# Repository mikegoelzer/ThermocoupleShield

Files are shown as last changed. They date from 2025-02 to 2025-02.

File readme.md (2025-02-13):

# Arduino K-Type Thermocouple Shield

<div align="center">
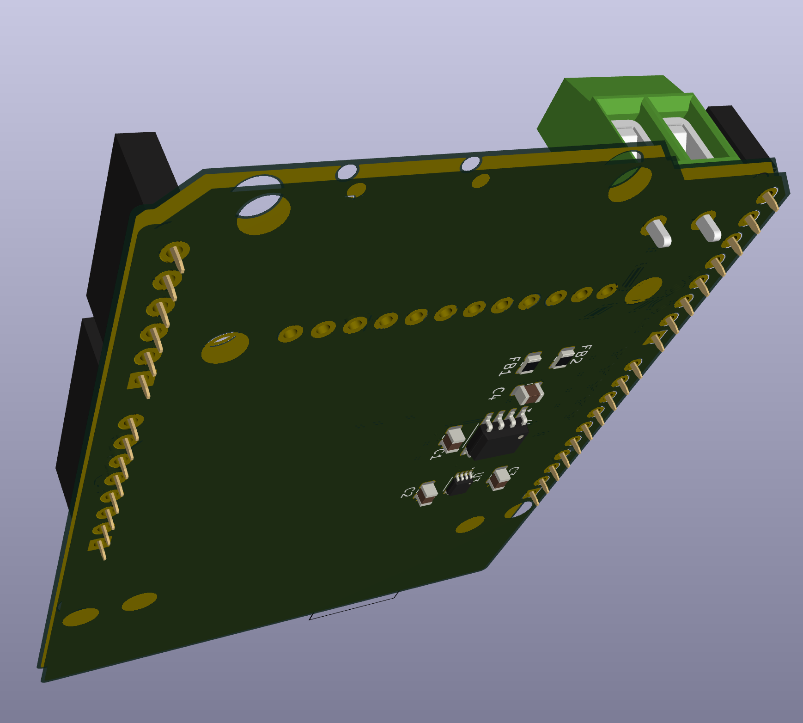
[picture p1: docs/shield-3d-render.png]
3D render of the thermocouple shield
  
</div>

## Description

Arduino Uno shield designed to interface with K-type thermocouples using the MAX31855 cold-junction compensated thermocouple-to-digital converter.

## Features

- Compatible with Arduino Uno form factor
- Uses MAX31855 for K-type thermocouple interface
- Display screen with Arduino sketch for displaying temperature
- Temperature range: -200°C to +1350°C

## Repository Contents

- `/hardware` - KiCad project files and custom parts
- `/doc` - documentation and images
- `/bom` - bill of materials spreadsheets
- 

## Hardware Requirements

- Arduino Uno or compatible board
- K-type thermocouple
- This shield PCB

## License

This hardware design is released under the [CERN Open Hardware License v2 - Strongly Reciprocal](https://ohwr.org/cern_ohl_s_v2.txt).

## Contributing

Contributions to improve the design are welcome. Please submit issues and pull requests.

# Credits

Circuit inspired by [Adafruit #269](https://www.adafruit.com/product/269)

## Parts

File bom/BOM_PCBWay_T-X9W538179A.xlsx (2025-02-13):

 |  |  | T-X9W538179A 01PCS BOM
Item # | *Designator | *Qty | Manufacturer | *Mfg Part # | Description / Value | *Package/Footprint | Type | Your Instructions / Notes
1 | U2 | 1 | Knitter-Switch | PLSJ 1 | SWITCH TACT 10MA 5V | Custom footprint | SMD
2 | U1 | 1 | Analog Devices Inc./Maxim Integrated | MAX31855KASA+T | IC CONV THERMOCOUPLE-DGTL SOIC | 8-SOIC | SMD
3 | C1,C2,C3 | 3 | YAGEO | CC0805KRX7R9BB104 | CAP CER 0.1UF 50V X7R 0805 | 0805 | SMD
4 | C4 | 1 | KEMET | C0805C103K5RACTU | CAP CER 10000PF 50V X7R 0805 | 0805 | SMD
5 | FB1,FB2 | 2 | Würth Elektronik | 74279220601 | FERRITE BEAD 600 OHM 0805 1LN | 0805 | SMD
6 | J6 | 1 | Würth Elektronik | 691137710002 | TERM BLK 2POS SIDE ENTRY 5MM PCB | Custom footprint | THT
7 | U3 | 1 | Texas Instruments | TXB0102DCUR | IC TRANSLTR BIDIRECTIONAL 8VSSOP | 8-VSSOP | SMD
Need a quick and accurante quote? Need an efficient production? Please read SMT Ordering Necessary Files & Info in 1 minute. Thank you very much! (https://www.pcbway.com/smt_ordering_guide.html)
Click for Instructions on How to Create a BOM (https://www.pcbway.com/blog/PCB_Assembly/How_to_Build_a_BOM__Bill_Of_Materials_.html)

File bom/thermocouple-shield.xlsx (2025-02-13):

Desc | Parts | Actual Qty | Order Qty | (Override Qty) | Order Qtr | Price | Subtotal | In basket? | Vendor URL | Mfgr | MPN | Notes
Thermocouple Shield Rev 1
# of boards | 2
CONN RCPT 10POS 0.1 GOLD PCB | J2 | 1 | 2 |  | 2 | $2.02 | $4.04 | ✅ | https://www.digikey.com/en/products/detail/samtec-inc/SSQ-110-03-F-S/6678747 | Samtec | SSQ-110-03-F-S
CONN RCPT 8POS 0.1 GOLD PCB | J1,J4 | 2 | 4 |  | 4 | $1.86 | $7.44 | ✅ | https://www.digikey.com/en/products/detail/samtec-inc/SSQ-108-03-F-S/6692119 | Samtec | SSQ-108-03-F-S
CONN RCPT 6POS 0.1 GOLD PCB | J3 | 1 | 2 |  | 2 | $1.40 | $2.80 | ✅ | https://www.digikey.com/en/products/detail/samtec-inc/SSQ-106-03-F-S/6678741 | Samtec | SSQ-106-03-F-S
RECEPTACLE STRIP 12P 2.54MM PITC | J5 | 1 | 2 |  | 2 | $1.40 | $2.80 | ✅ | https://www.digikey.com/en/products/detail/adam-tech/RS1-12-G/9832041 | Adam Tech | RS1-12-G

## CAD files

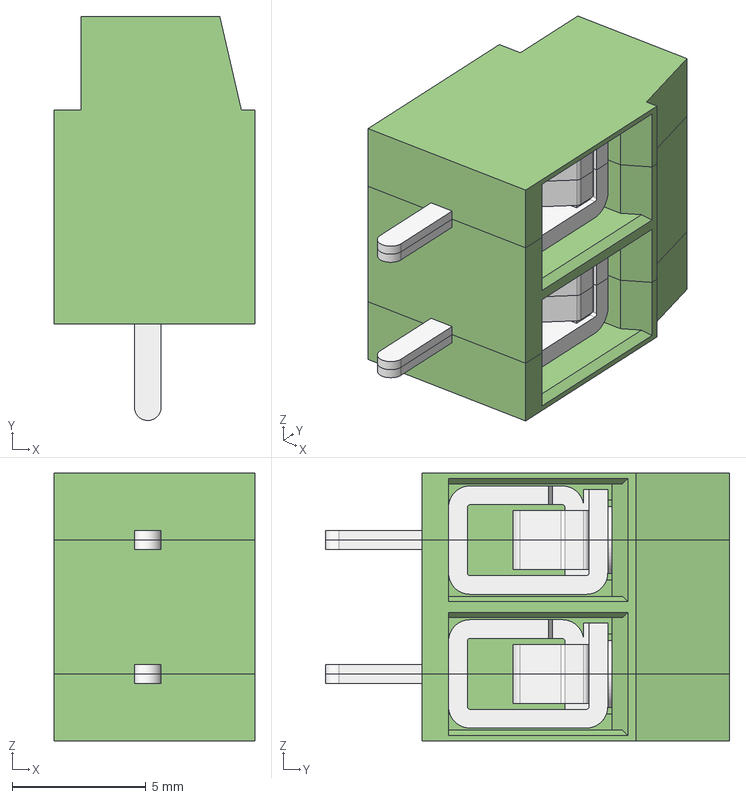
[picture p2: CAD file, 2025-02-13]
hardware/parts/691137710002/691137710002.step
7.50 x 15.1 x 10.0 mm
MRT12P5_SX
MRT12P5_CNT
MRT12P5_DX

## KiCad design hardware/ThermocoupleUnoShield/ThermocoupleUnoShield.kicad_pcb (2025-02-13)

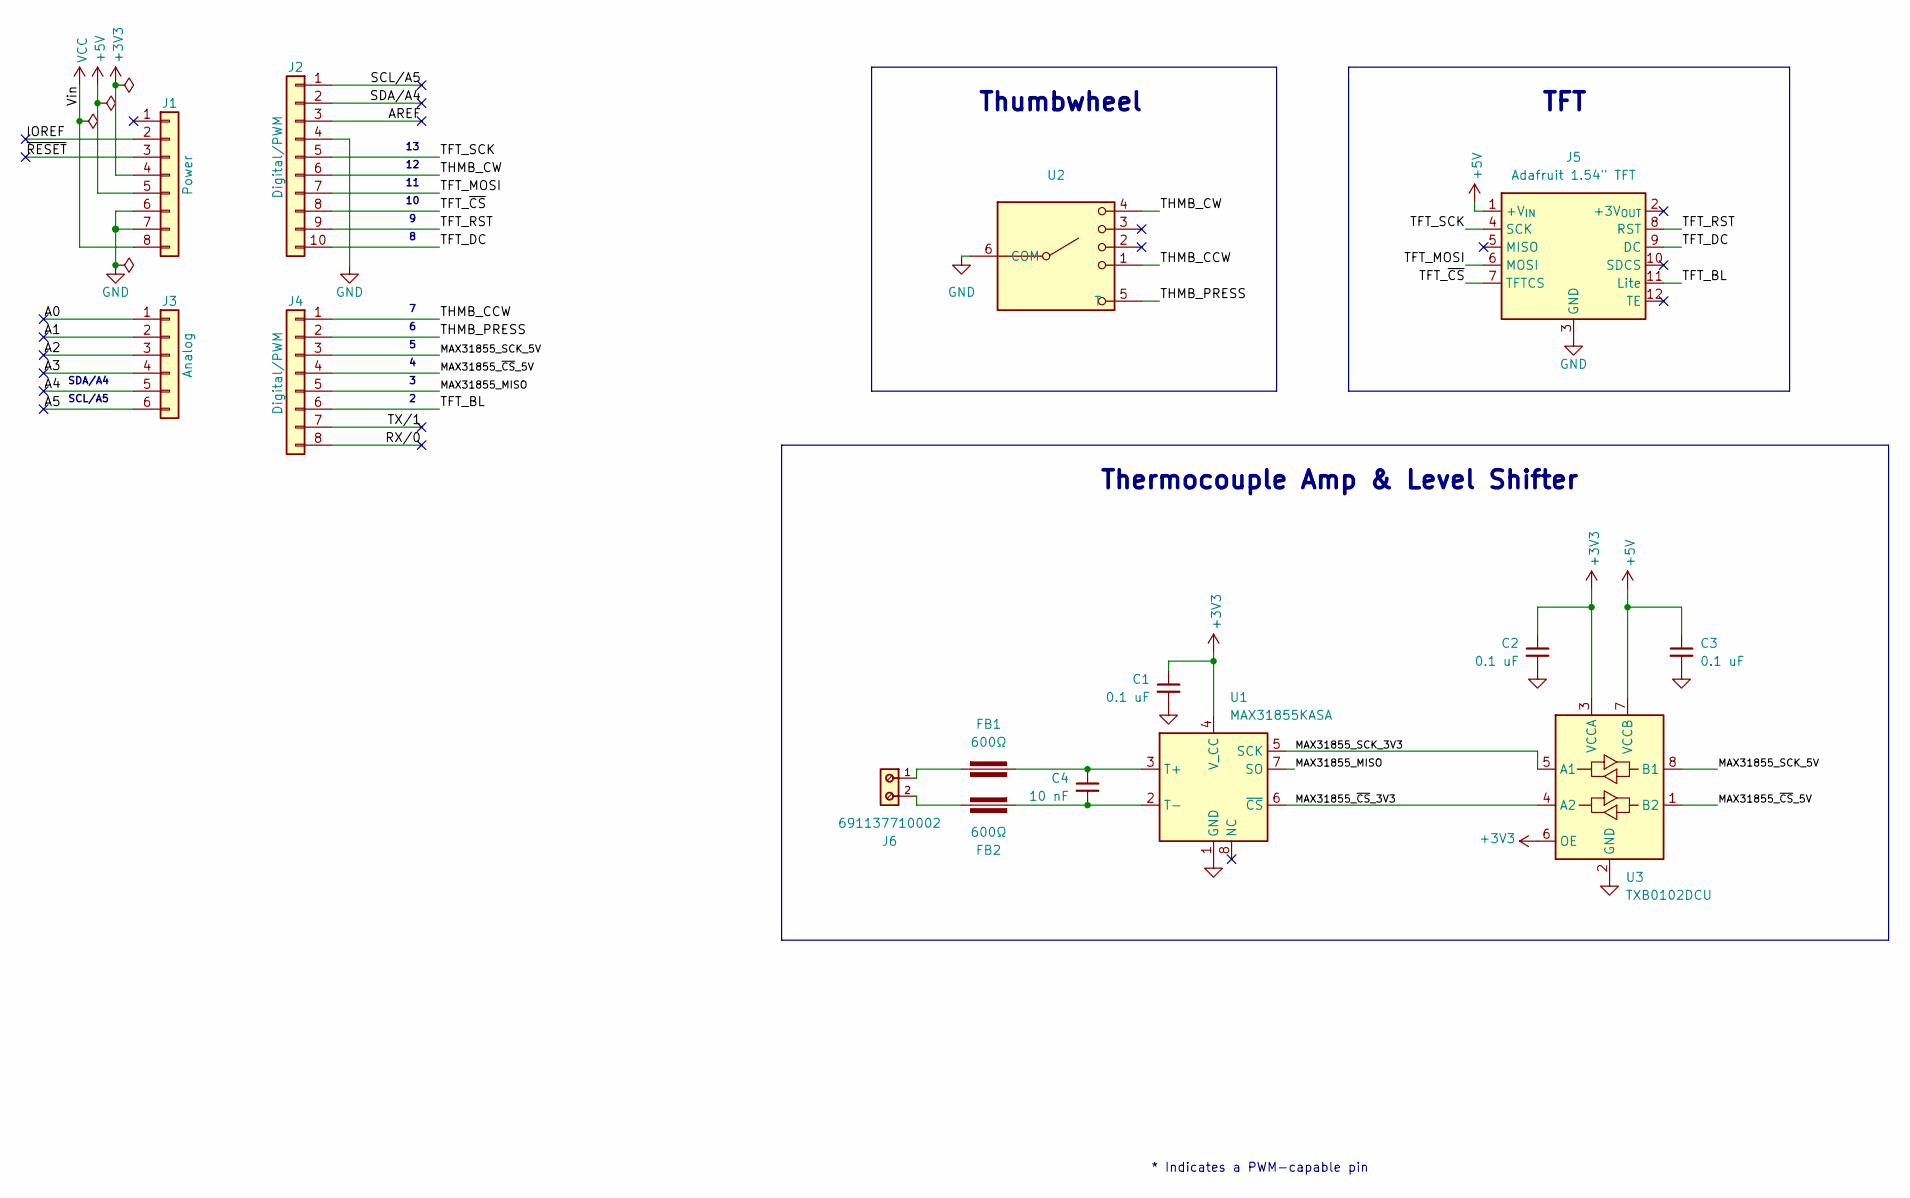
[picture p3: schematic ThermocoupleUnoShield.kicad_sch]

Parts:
C1, C2, C3: 0.1 uF; C_0805_2012Metric; MPN CC0805KRX7R9BB104
C4: 10 nF; C_0805_2012Metric; MPN C0805C103K5RACTU
FB1, FB2: 600Ω; Fuse_0805_2012Metric; MPN 74279220601
J1: Power; PinSocket_1x08_P2.54mm_Vertical; MPN SSQ-108-03-F-S
J2: Digital/PWM; PinSocket_1x10_P2.54mm_Vertical; MPN SSQ-110-03-F-S
J3: Analog; PinSocket_1x06_P2.54mm_Vertical; MPN SSQ-106-03-F-S
J4: Digital/PWM; PinSocket_1x08_P2.54mm_Vertical; MPN SSQ-108-03-F-S
J5: Adafruit 1.54" TFT; 1.54 TFT 240x240; MPN 3787
J6: 691137710002; PART-NUMBER 691137710002
U1: MAX31855KASA; SOIC-8_3.9x4.9mm_P1.27mm; MPN MAX31855KASA+T
U2: PLSJ1; MPN PLSJ 1
U3: TXB0102DCU; VSSOP-8_2.4x2.1mm_P0.5mm; MPN TXB0102DCUR

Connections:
+3V3: C1.1, C2.1, J1.4, U1.4 (V_CC), U3.3 (VCCA), U3.6 (OE)
+5V: C3.1, J1.5, J5.1 (+V_{IN}), U3.7 (VCCB)
/A0: J3.1
/A1: J3.2
/A2: J3.3
/A3: J3.4
/A4: J3.5
/A5: J3.6
/AREF: J2.3
/IOREF: J1.2
/MAX31855_MISO: J4.5, U1.7 (SO)
/MAX31855_SCK_3V3: U1.5 (SCK), U3.5 (A1)
/MAX31855_SCK_5V: J4.3, U3.8 (B1)
/MAX31855_~CS_3V3: U1.6 (~CS), U3.4 (A2)
/MAX31855_~CS_5V: J4.4, U3.1 (B2)
/RX/0: J4.8
/SCL/A5: J2.1
/SDA/A4: J2.2
/TFT_BL: J4.6, J5.11 (Lite)
/TFT_DC: J2.10, J5.9 (DC)
/TFT_MOSI: J2.7, J5.6 (MOSI)
/TFT_RST: J2.9, J5.8 (RST)
/TFT_SCK: J2.5, J5.4 (SCK)
/TFT_~CS: J2.8, J5.7 (TFTCS)
/THMB_CCW: J4.1, U2.1
/THMB_CW: J2.6, U2.4
/THMB_PRESS: J4.2, U2.5 (T)
/TX/1: J4.7
/~RESET: J1.3
GND: C1.2, C2.2, C3.2, J1.6, J1.7, J2.4, J5.3 (GND), U1.1 (GND), U2.6 (COM), U3.2 (GND)
unnamed: FB1.1, J6.1
unnamed: FB2.2, J6.2
unnamed: C4.1, FB1.2, U1.3 (T+)
unnamed: C4.2, FB2.1, U1.2 (T-)
VCC: J1.8

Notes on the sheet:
Thumbwheel
TFT
SCL/A5
* Indicates a PWM-capable pin
SDA/A4
Thermocouple Amp & Level Shifter

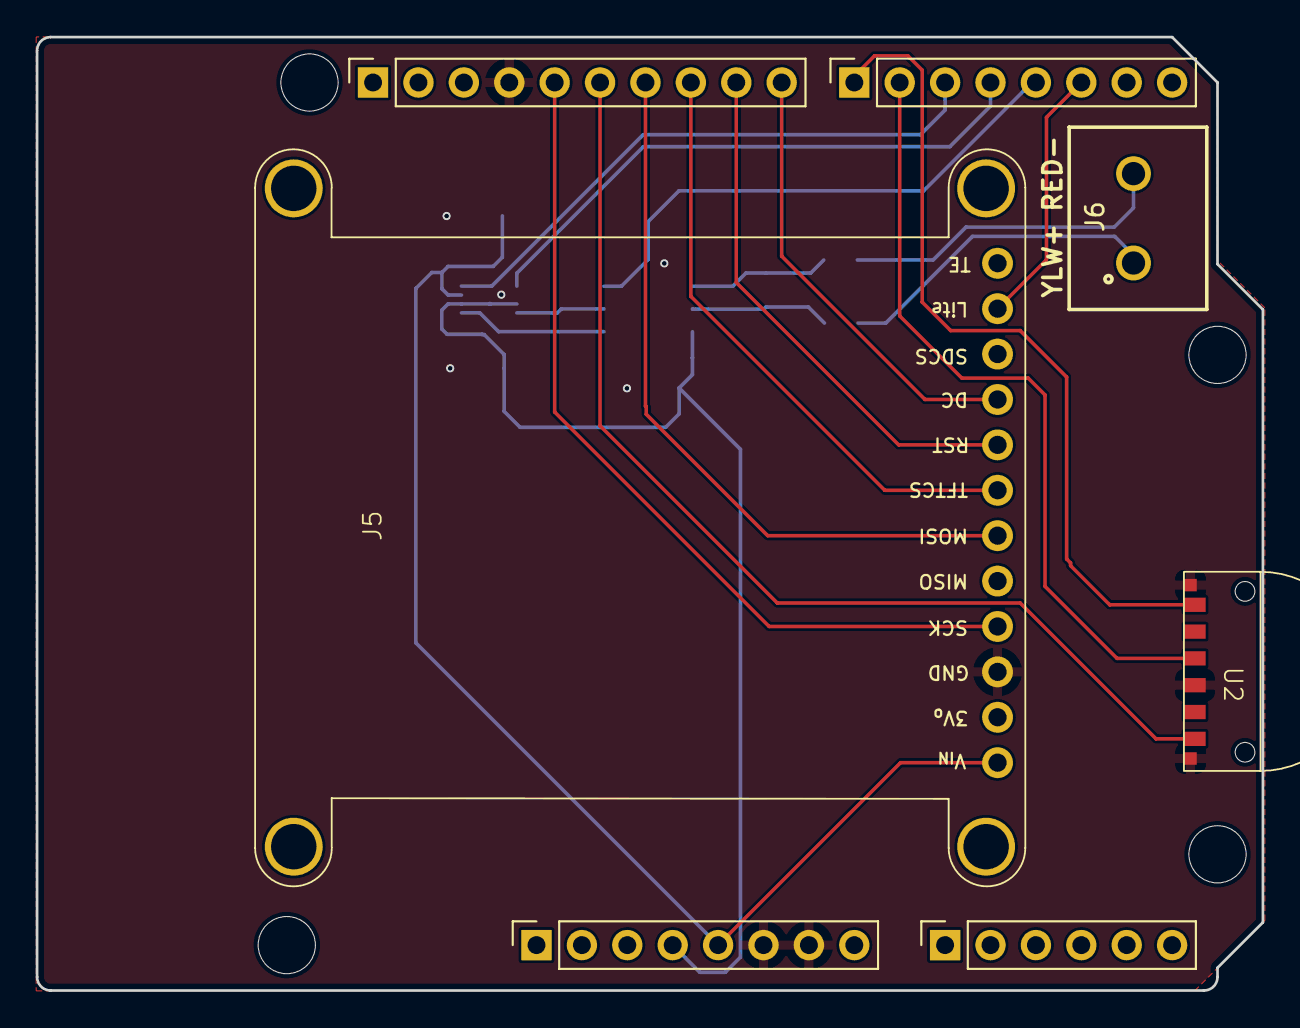
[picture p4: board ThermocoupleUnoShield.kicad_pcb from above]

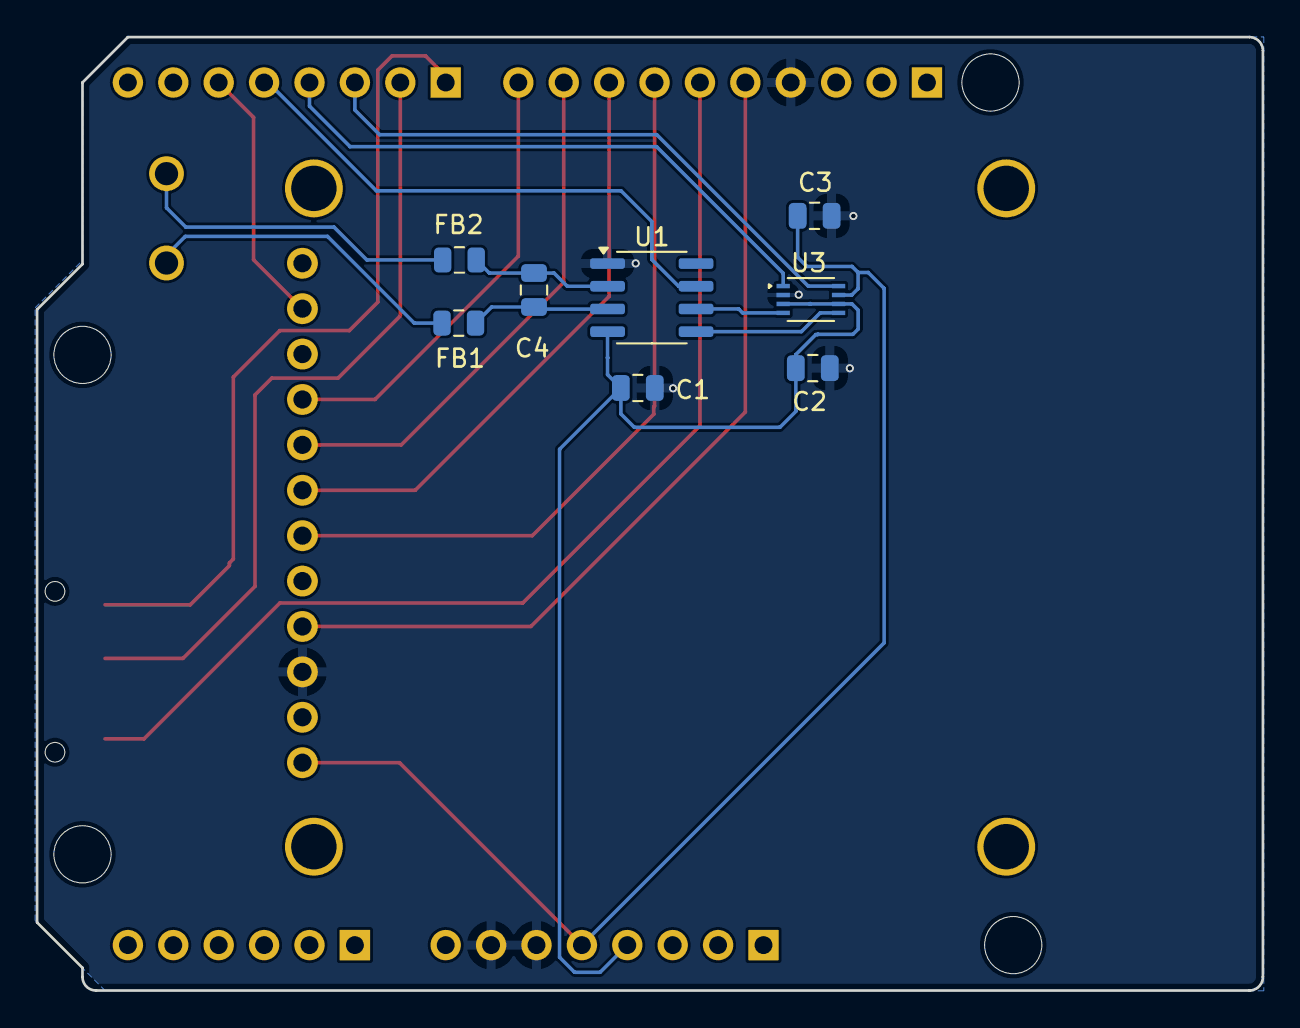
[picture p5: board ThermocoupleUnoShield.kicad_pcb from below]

Board: 2 copper layers, 68.6 x 53.3 mm, 19 parts (8 on the bottom side), 21 nets.

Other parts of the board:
MH1, MH2, MH3, MH4: MountingHole_3.2mm
